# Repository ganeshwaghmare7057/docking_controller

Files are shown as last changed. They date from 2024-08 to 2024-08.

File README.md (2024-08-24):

# Dose droid medicine packing machine (Docking controller)
  Description: Dose droid is medicine packing machine, docking controller is one part of machine. I designed PCB and I use ATmega328 controller chip. Collecting two module QRT13GR sensor and encoder. I used UART and SPI communication protocol.

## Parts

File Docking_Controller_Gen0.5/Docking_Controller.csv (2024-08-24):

Column2 | Designator | Footprint | Quantity | Designation | Type
1 | D1 | D_SMA_Handsoldering | 1 | M7 | Diode
2 | Spare | B3BPHSM4TBTLFSN | 1 | Spare_Pins | JST SMD
3 | RESP4,RESP2 | R_0805_2012Metric_Pad1.20x1.40mm_HandSolder | 2 | 5.6K | RMD 0805
4 | C2,C5,C7,C9 | C_0805_2012Metric_Pad1.18x1.45mm_HandSolder | 4 | 0.1uF | Ccap SMD 0805
5 | RESP3,RESP5 | R_0805_2012Metric_Pad1.20x1.40mm_HandSolder | 2 | 4.3K | R SMD 0805
6 | |1 | CP_Elec_8x10.5 | 1 | 220uF 50V | Ecap
7 | CESP1 | CP_EIA-3216-18_Kemet-A_Pad1.58x1.35mm_HandSolder | 1 | 10uf/16v Tantalum | Cap SMD Tantalum
8 | C10 | C_0805_2012Metric_Pad1.18x1.45mm_HandSolder | 1 | 0.1uf | Ccap SMD 0805
9 | J2 | B5BPHSM4TBTLFSN | 1 | ENCODER | JST SMD 0805
10 | RESP1 | R_0805_2012Metric_Pad1.20x1.40mm_HandSolder | 1 | 10k | R SMD 0805
11 | C8,C3,C6,C1,C4 | C_1206_3216Metric_Pad1.33x1.80mm_HandSolder | 5 | 1uF | Ccap SMD 1206
13 | D2 | LED_1206_3216Metric_Pad1.42x1.75mm_HandSolder | 1 | 12v-LED | LED SMD
14 | R2,R1 | R_0805_2012Metric_Pad1.20x1.40mm_HandSolder | 2 | 2.2k | R SMD 0805
15 | U2 | TQFP-32_7x7mm_P0.8mm | 1 | ATmega328P-A | IC
16 | D3 | LED_D3.0mm_Horizontal_O1.27mm_Z2.0mm | 1 | SLOT_LED | LED SMD 0805
17 | D4 | LED_0805_2012Metric_Pad1.15x1.40mm_HandSolder | 1 | SLOT_LED | LED SMD 0805
18 | C11,C12 | C_0805_2012Metric_Pad1.18x1.45mm_HandSolder | 2 | 22pF | C SMD 0805
19 | U1 | SOT-223-3_TabPin2 | 1 | AMS1117-5.0 | AMS 5V SMD
20 | Y1 | Crystal_HC49-U_Vertical | 1 | 16MHz | TH Crystal
21 | SW1 | SW_Tactile_Straight_KSA0Axx1LFTR | 1 | RST | pushbutton Switch
22 | J1 | TerminalBlock_Altech_AK300-2_P5.00mm | 1 | Power_Supply | 2 PIN Screw Terminal
23 | J4 | B5BPHSM4TBTLFSN | 1 | UART | JST 5PIN SMD
24 | J6 | B3BPHSM4TBTLFSN | 1 | HOME_SLOT | JST 3PIN SMD
25 | J3 | PinHeader_1x06_P2.54mm_Vertical | 1 | ICSP | PinHeader
26 | F1 | Fuse_1812_4532Metric_Pad1.30x3.40mm_HandSolder | 1 | 16V 3A PPTC | Fuse SMD 1812
27 | J5 | B5BPHSM4TBTLFSN | 1 | Docking Sensor | JST 5PIN SMD
28 | |2 | CP_EIA-3216-18_Kemet-A_Pad1.58x1.35mm_HandSolder | 1 | 10uF/16V Tantalum | C SMD Tantlum 0805

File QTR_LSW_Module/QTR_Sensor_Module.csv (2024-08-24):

Id | Designator | Footprint | Quantity | Designation
1 | RMOS3 | R_0805_2012Metric_Pad1.20x1.40mm_HandSolder | 1 | 10k
2 | H1,H2 | MountingHole_2.2mm_M2 | 2 | MountingHole
3 | RMOS2,RMOS5,RMOS1 | R_0805_2012Metric_Pad1.20x1.40mm_HandSolder | 3 | 220E
4 | U1 | OnSemi_CASE100CY | 1 | QRE1113GR
5 | RMOS4 | R_0805_2012Metric_Pad1.20x1.40mm_HandSolder | 1 | 1K
6 | R1 | R_0805_2012Metric_Pad1.20x1.40mm_HandSolder | 1 | 2.2k
7 | J3 | JST_PH_S2B-PH-SM4-TB_1x02-1MP_P2.00mm_Horizontal | 1 | LSW
8 | U3 | SO08 | 1 | LM393
9 | D1 | LED_1206_3216Metric_Pad1.42x1.75mm_HandSolder | 1 | 5V-LED
10 | J2 | PinHeader_1x03_P2.54mm_Vertical | 1 | Jumper
11 | RV1 | TRIM_3362P-1-151 | 1 | 10K Pot
12 | J1 | B5BPHSM4TBTLFSN | 1 | Connector
13 | U2 | DIP-4_W7.62mm | 1 | PC817

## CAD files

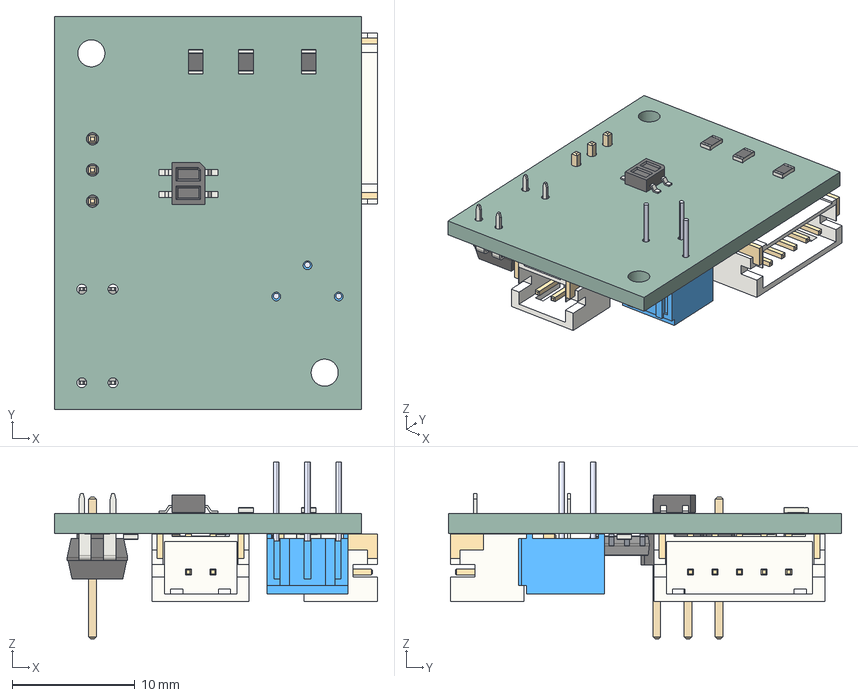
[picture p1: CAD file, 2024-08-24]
QTR_LSW_Module/QTR_Sensor_Module2.step
26.3 x 32.0 x 14.4 mm
R_0805_2012Metric x 6
OnSemi_CASE100CY
S3B-PH-SM4-TB v12 x 2
ASSEMBLY
LED_1206_3216Metric
PinHeader_1x03_P254mm_Vertical
3362P-1-103
DIP-4_W7.62mm
QTR_Sensor_Module PCB

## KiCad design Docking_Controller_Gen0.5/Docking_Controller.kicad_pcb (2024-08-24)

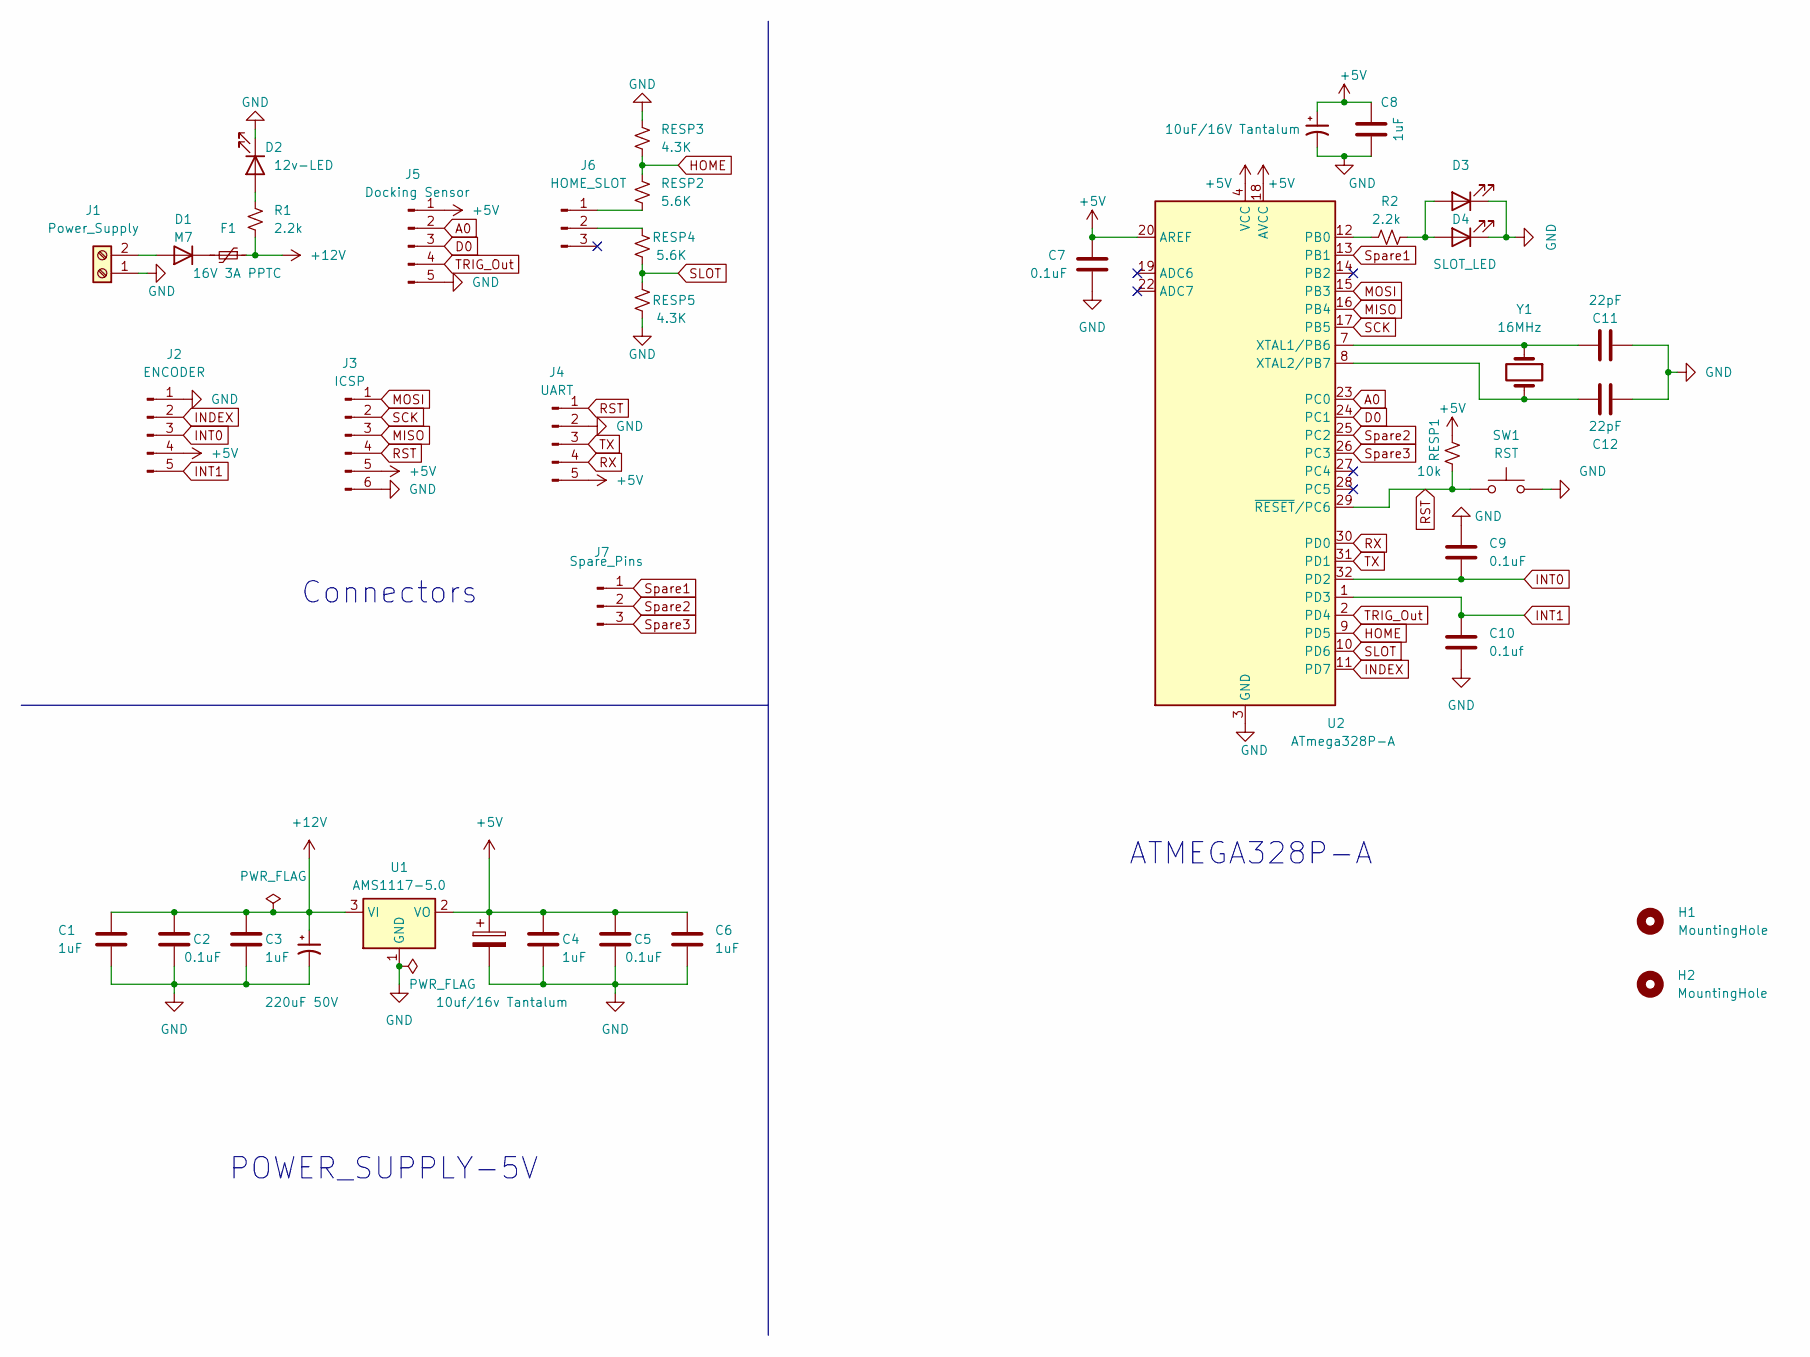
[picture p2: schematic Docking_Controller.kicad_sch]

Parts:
C1, C3, C4, C6, C8: 1uF; C_1206_3216Metric_Pad1.33x1.80mm_HandSolder
C2, C5, C7, C9: 0.1uF; C_0805_2012Metric_Pad1.18x1.45mm_HandSolder
C10: 0.1uf; C_0805_2012Metric_Pad1.18x1.45mm_HandSolder
C11, C12: 22pF; C_0805_2012Metric_Pad1.18x1.45mm_HandSolder
CESP1: 10uf/16v Tantalum; CP_EIA-3216-18_Kemet-A_Pad1.58x1.35mm_HandSolder
D1: M7; D_SMA_Handsoldering
D2: 12v-LED; LED_1206_3216Metric_Pad1.42x1.75mm_HandSolder
D3: SLOT_LED; LED_D3.0mm_Horizontal_O1.27mm_Z2.0mm
D4: SLOT_LED; LED_0805_2012Metric_Pad1.15x1.40mm_HandSolder
F1: 16V 3A PPTC; Fuse_1812_4532Metric_Pad1.30x3.40mm_HandSolder
H1, H2: MountingHole; MountingHole_3.2mm_M3
J1: Power_Supply; TerminalBlock_Altech_AK300-2_P5.00mm
J2: ENCODER; B5BPHSM4TBTLFSN
J3: ICSP; PinHeader_1x06_P2.54mm_Vertical
J4: UART; B5BPHSM4TBTLFSN
J5: Docking Sensor; B5BPHSM4TBTLFSN
J6: HOME_SLOT; B3BPHSM4TBTLFSN
J7: Spare_Pins; B3BPHSM4TBTLFSN
R1, R2: 2.2k; R_0805_2012Metric_Pad1.20x1.40mm_HandSolder
RESP1: 10k; R_0805_2012Metric_Pad1.20x1.40mm_HandSolder
RESP2, RESP4: 5.6K; R_0805_2012Metric_Pad1.20x1.40mm_HandSolder
RESP3, RESP5: 4.3K; R_0805_2012Metric_Pad1.20x1.40mm_HandSolder
SW1: RST; SW_Tactile_Straight_KSA0Axx1LFTR
U1: AMS1117-5.0; SOT-223-3_TabPin2
U2: ATmega328P-A; TQFP-32_7x7mm_P0.8mm
Y1: 16MHz; Crystal_HC49-U_Vertical
|1: 220uF 50V; CP_Elec_8x10.5
|2: 10uF/16V Tantalum; CP_EIA-3216-18_Kemet-A_Pad1.58x1.35mm_HandSolder

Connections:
+5V: C4.1, C5.1, C6.1, C7.1, C8.1, CESP1.1, J2.4, J3.5, J4.5, J5.1, RESP1.1, U1.2 (VO), U2.4 (VCC), U2.6 (VCC), U2.18 (AVCC), U2.20 (AREF), |2.1
+12V: C1.1, C2.1, C3.1, F1.1, R1.2, U1.3 (VI), |1.1
A0: J5.2, U2.23 (PC0)
D0: J5.3, U2.24 (PC1)
GND: C1.2, C2.2, C3.2, C4.2, C5.2, C6.2, C7.2, C8.2, C9.1, C10.2, C11.1, C12.1, CESP1.2, D2.1 (K), D3.1 (K), D4.1 (K), J1.1, J2.1, J3.6, J4.2, J5.5, RESP3.1, RESP5.1, SW1.2, U1.1 (GND), U2.3 (GND), U2.5 (GND), U2.21 (GND), |1.2, |2.2
HOME: RESP2.1, RESP3.2, U2.9 (PD5)
INDEX: J2.2, U2.11 (PD7)
INT0: C9.2, J2.3, U2.32 (PD2)
INT1: C10.1, J2.5, U2.1 (PD3)
MISO: J3.3, U2.16 (PB4)
MOSI: J3.1, U2.15 (PB3)
unnamed: D1.2 (A), J1.2
unnamed: D1.1 (K), F1.2
unnamed: D2.2 (A), R1.1
unnamed: D3.2 (A), D4.2 (A), R2.1
unnamed: J6.1, RESP2.2
unnamed: J6.2, RESP4.2
unnamed: R2.2, U2.12 (PB0)
unnamed: C11.2, U2.7 (XTAL1/PB6), Y1.1
unnamed: C12.2, U2.8 (XTAL2/PB7), Y1.2
RST: J3.4, J4.1, RESP1.2, SW1.1, U2.29 (~RESET/PC6)
RX: J4.4, U2.30 (PD0)
SCK: J3.2, U2.17 (PB5)
SLOT: RESP4.1, RESP5.2, U2.10 (PD6)
Spare1: J7.1, U2.13 (PB1); also elsewhere on the board
Spare2: J7.2, U2.25 (PC2); also elsewhere on the board
Spare3: J7.3, U2.26 (PC3); also elsewhere on the board
TRIG_Out: J5.4, U2.2 (PD4)
TX: J4.3, U2.31 (PD1)

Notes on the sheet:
Connectors
ATMEGA328P-A
POWER_SUPPLY-5V

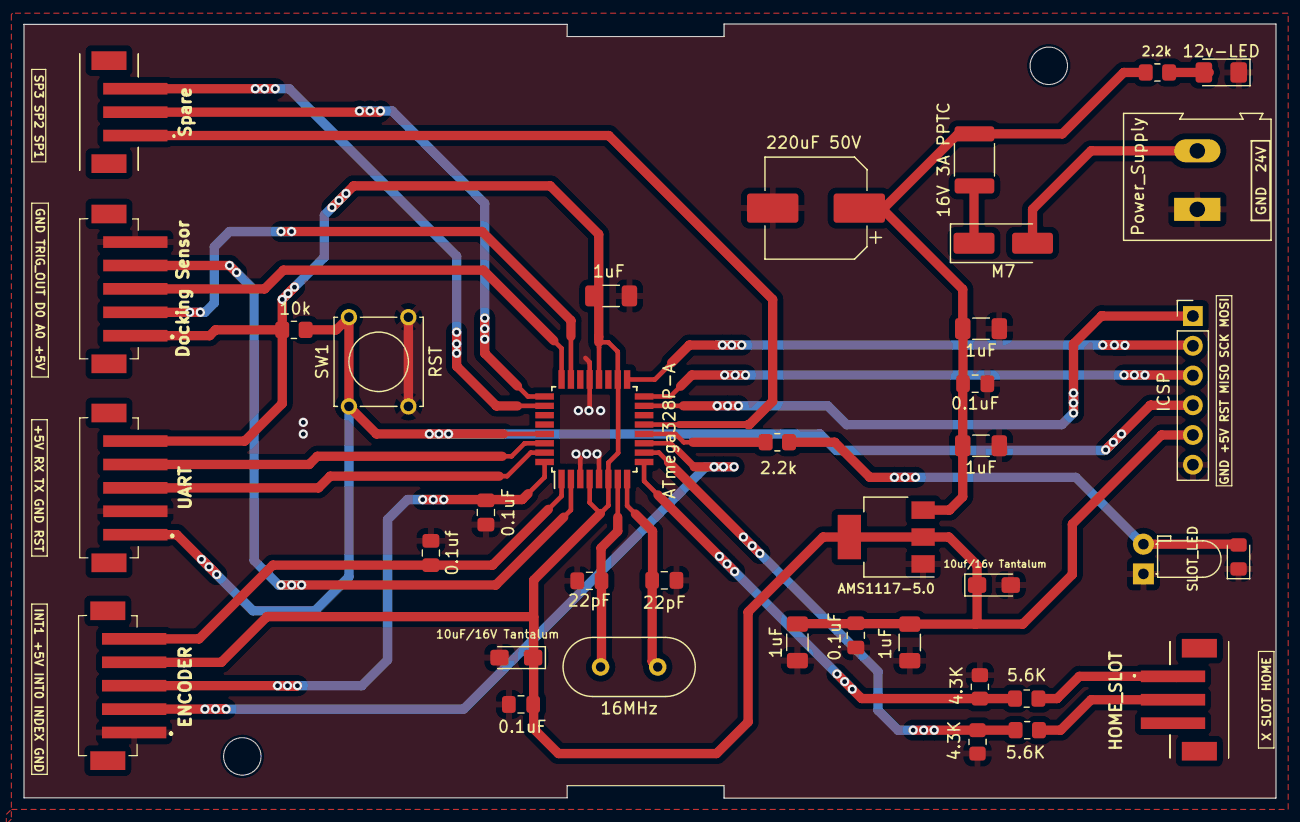
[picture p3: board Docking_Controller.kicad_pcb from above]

Board: 2 copper layers, 107.0 x 66.1 mm, 40 parts (0 on the bottom side), 29 nets.

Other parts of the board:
Spare: Spare_Pins; B3BPHSM4TBTLFSN

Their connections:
Spare1: Spare.1; also elsewhere on the board
Spare2: Spare.2; also elsewhere on the board
Spare3: Spare.3; also elsewhere on the board

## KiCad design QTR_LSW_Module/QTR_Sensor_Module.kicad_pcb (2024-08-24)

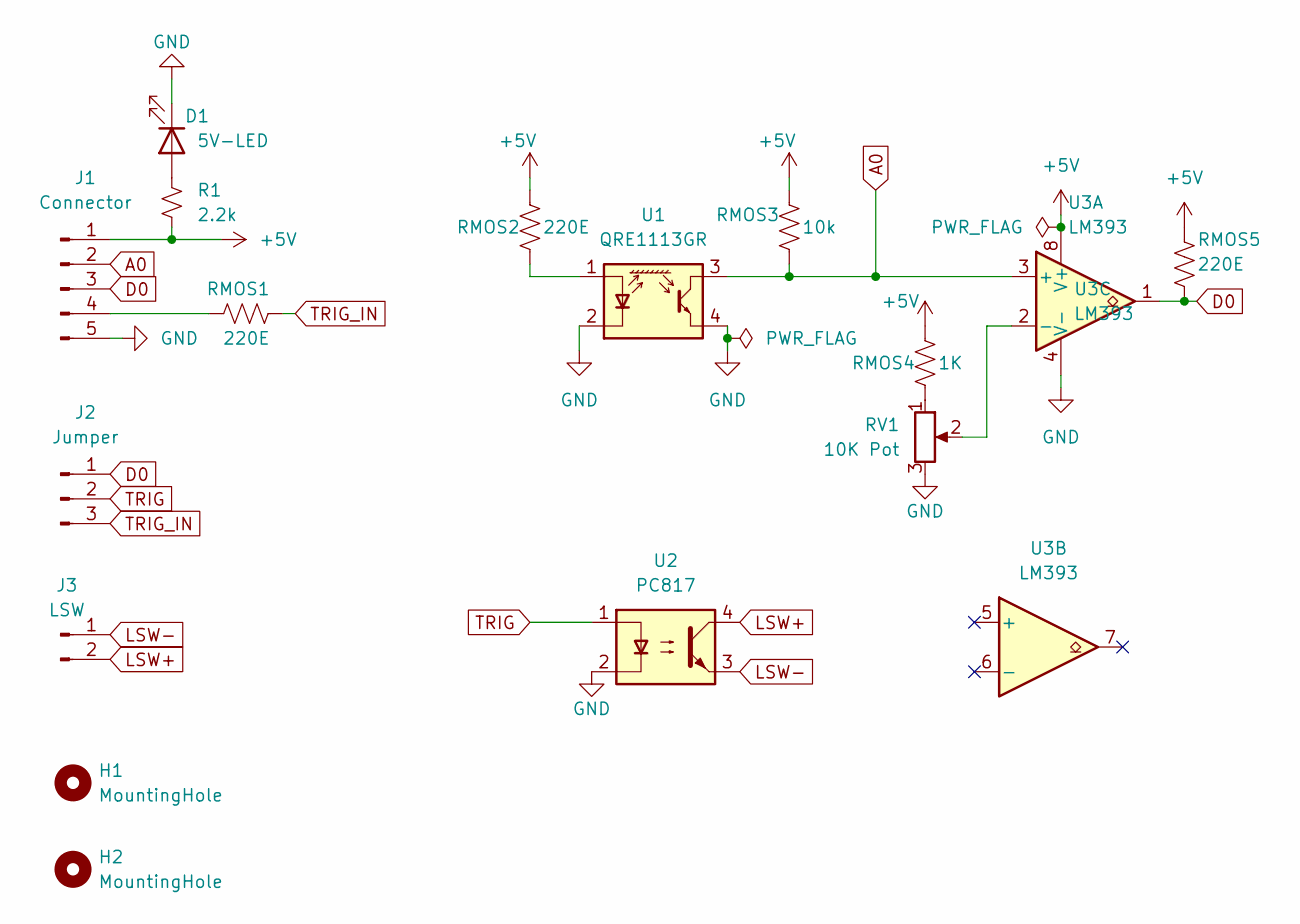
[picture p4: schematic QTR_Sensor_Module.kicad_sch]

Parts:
D1: 5V-LED; LED_1206_3216Metric_Pad1.42x1.75mm_HandSolder
H1, H2: MountingHole; MountingHole_2.2mm_M2
J1: Connector; B5BPHSM4TBTLFSN
J2: Jumper; PinHeader_1x03_P2.54mm_Vertical
J3: LSW; JST_PH_S2B-PH-SM4-TB_1x02-1MP_P2.00mm_Horizontal
R1: 2.2k; R_0805_2012Metric_Pad1.20x1.40mm_HandSolder
RMOS1, RMOS2, RMOS5: 220E; R_0805_2012Metric_Pad1.20x1.40mm_HandSolder
RMOS3: 10k; R_0805_2012Metric_Pad1.20x1.40mm_HandSolder
RMOS4: 1K; R_0805_2012Metric_Pad1.20x1.40mm_HandSolder
RV1: 10K Pot; TRIM_3362P-1-151
U1: QRE1113GR; OnSemi_CASE100CY
U2: PC817; DIP-4_W7.62mm
U3: LM393; SO08

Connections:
+5V: J1.1, R1.2, RMOS2.2, RMOS3.2, RMOS4.2, RMOS5.2, U3.8 (V+)
A0: J1.2, RMOS3.1, U1.3, U3.3 (+)
D0: J1.3, J2.1, RMOS5.1, U3.1
GND: D1.1 (K), J1.5, RV1.3, U1.2 (K), U1.4, U2.2, U3.4 (V-)
LSW+: J3.2, U2.4
LSW-: J3.1, U2.3
unnamed: D1.2 (A), R1.1
unnamed: J1.4, RMOS1.2
unnamed: RMOS4.1, RV1.1
unnamed: RMOS2.1, U1.1 (A)
unnamed: RV1.2, U3.2 (-)
TRIG: J2.2, U2.1
TRIG_IN: J2.3, RMOS1.1

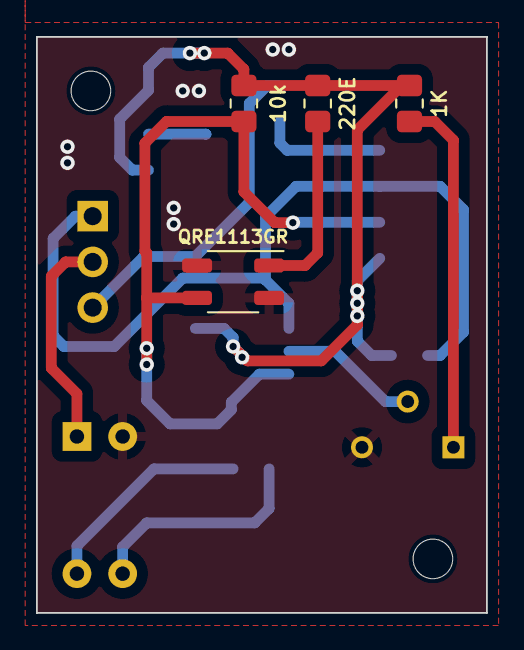
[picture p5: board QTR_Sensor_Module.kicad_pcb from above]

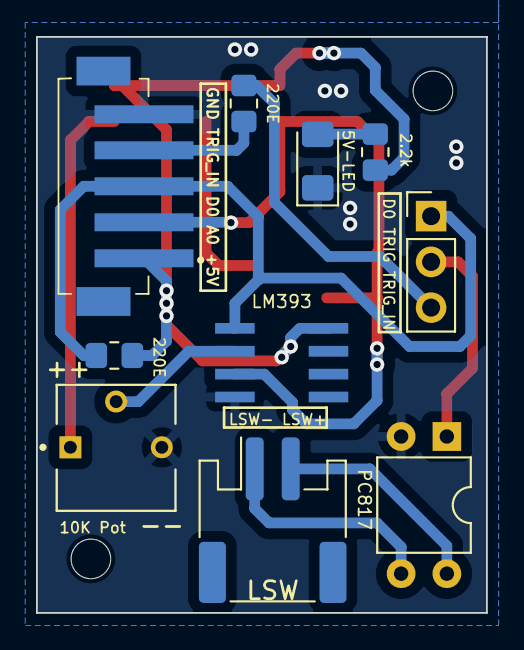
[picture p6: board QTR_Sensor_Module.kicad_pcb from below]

Board: 2 copper layers, 25.0 x 32.0 mm, 16 parts (10 on the bottom side), 13 nets.

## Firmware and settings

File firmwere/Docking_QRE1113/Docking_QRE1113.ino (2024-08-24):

int sensor_value;
int TRIGG_IN = 4;
void setup() 
{
  // put your setup code here, to run once:
  Serial.begin(115200);
  pinMode(A0, INPUT);
  pinMode(4, OUTPUT);
}
void loop() 
{
  // put your main code here, to run repeatedly: 
  sensor_value = (analogRead(A0));
  Serial.println(sensor_value);
  delay(500);

  if(sensor_value < 950)
  {
      Serial.println("Docked");
      digitalWrite(4, HIGH);
      delay(500);
  } 
  else
  { 
      Serial.println("Unlocked");
      digitalWrite(4, LOW);
      delay(500);  
  } 
}
